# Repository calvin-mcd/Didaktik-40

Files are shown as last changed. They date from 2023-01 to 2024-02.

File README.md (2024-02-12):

# Didaktik 40

The Didaktik 40 is a retro-style keyboard taking its inspiration form the czech homecomputer, the [didaktik gama](https://en.wikipedia.org/wiki/Didaktik#Didaktik_Gama). While offering its original layout, it also supports more modern split and single spacebar bottomrow configurations as well as two rotary encoders.
The case is designed by gizzle13. It is a 2 degree, 2 piece case with top mounting for either simple or burger topmounting. It uses an old-school unified daughterboard for the usb port. The case and pcb furthermore support 2 leds, just like on the original case, and another hole to access the reset button.

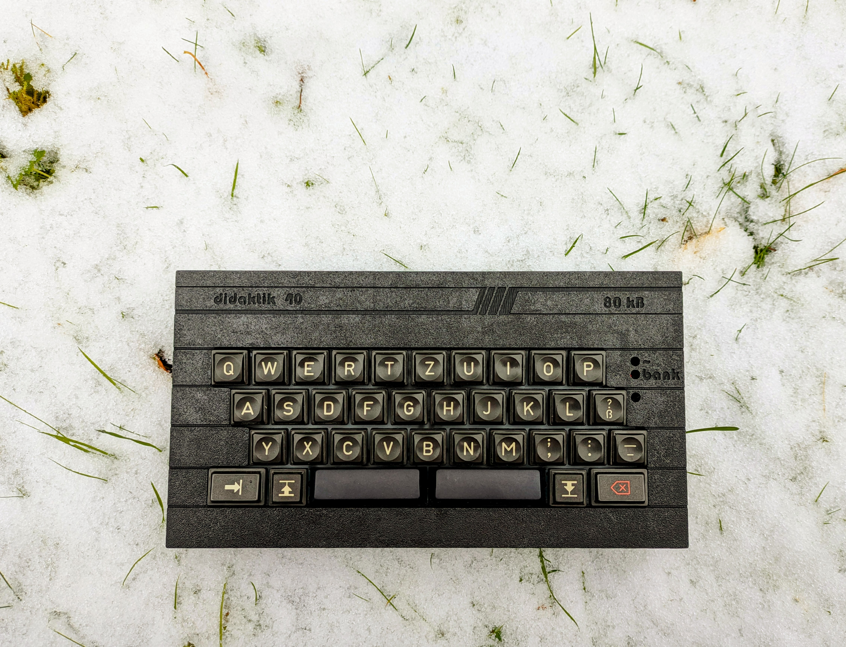
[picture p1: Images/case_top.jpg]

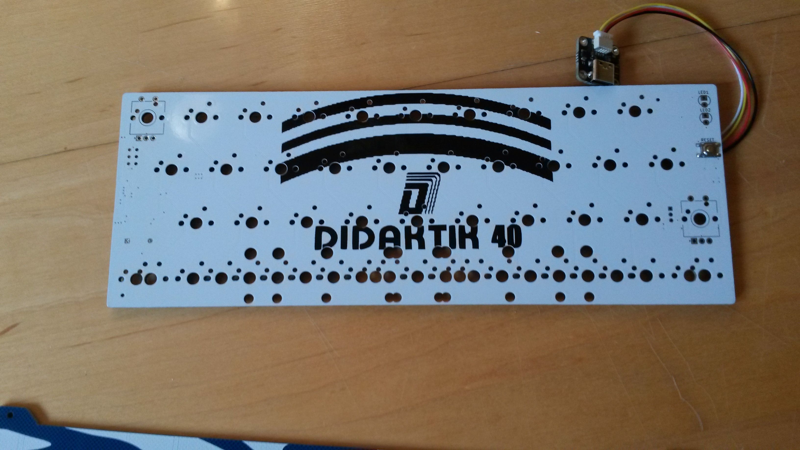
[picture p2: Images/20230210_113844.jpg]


## Layout

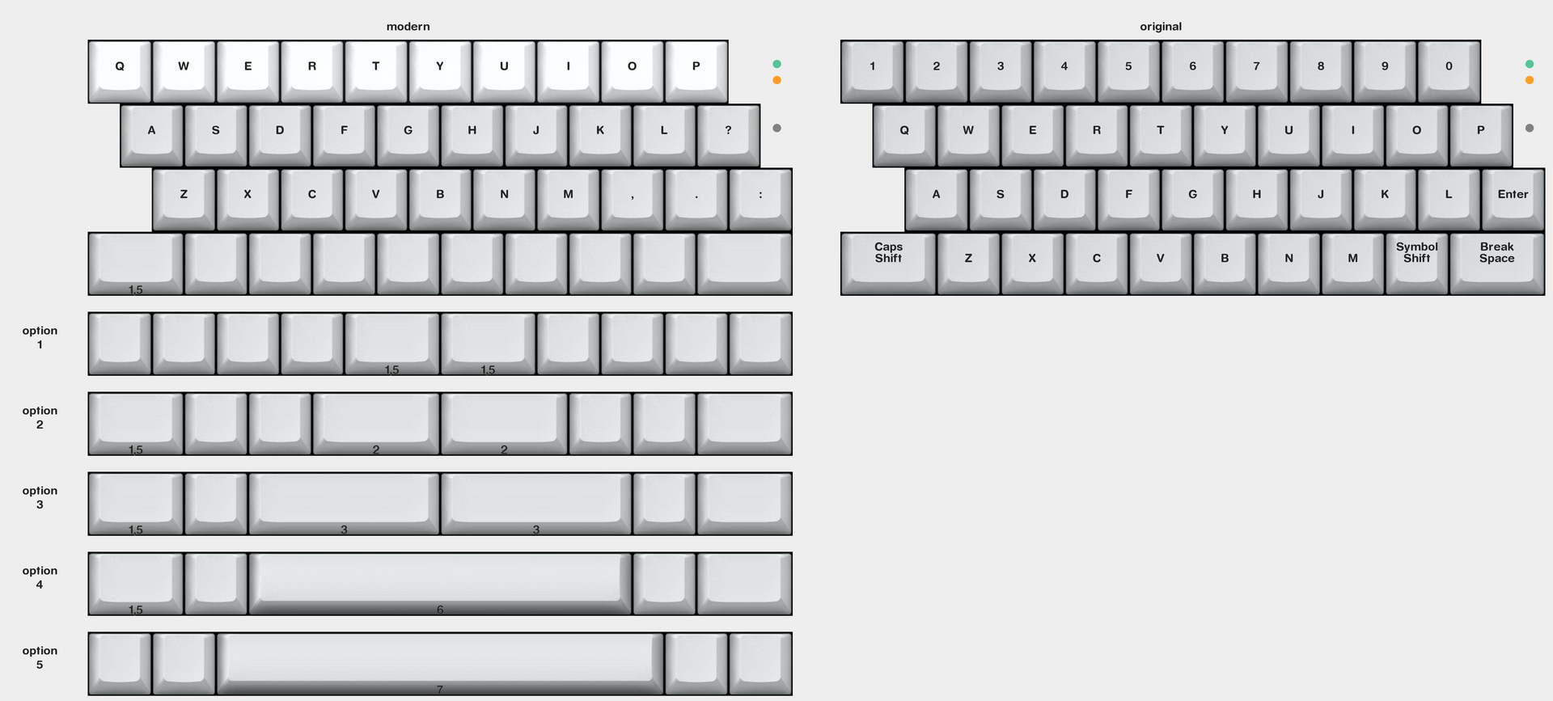
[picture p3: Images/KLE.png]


[Link](http://www.keyboard-layout-editor.com/#/gists/80f2dfd555ef09043852ad12f22f6b8f)

## Firmware

The basic firmware is set up to use the leds as layer indicators. Top for layer 1, bottom for layer 2, both for layer 3. There is hardware support for a speaker and for rgb strip but this is not enabled by default due to firmware size. Also note that the audio and rgb haven't been fully tested yet.

## Case

The case is designed by gizzle13. Case files can be found in the respective folder. It is designed to use m2 heatinserts. 

If you are in the EU consider asking gizzle to print the case for you to support them!

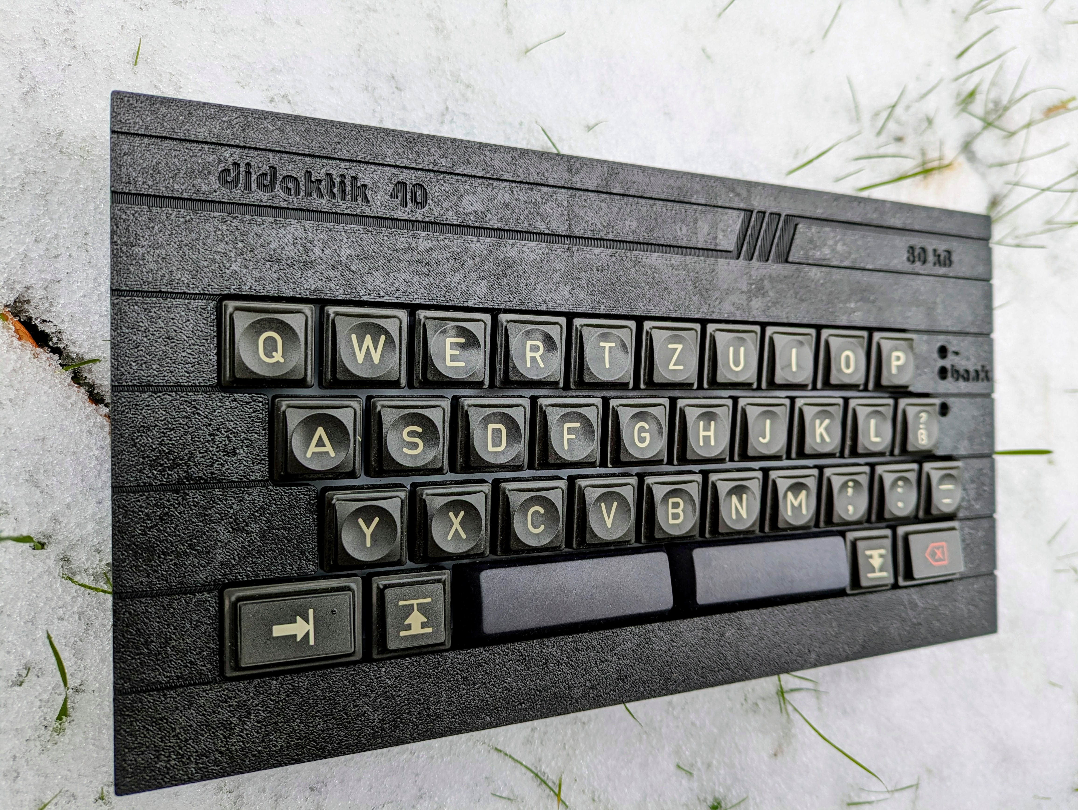
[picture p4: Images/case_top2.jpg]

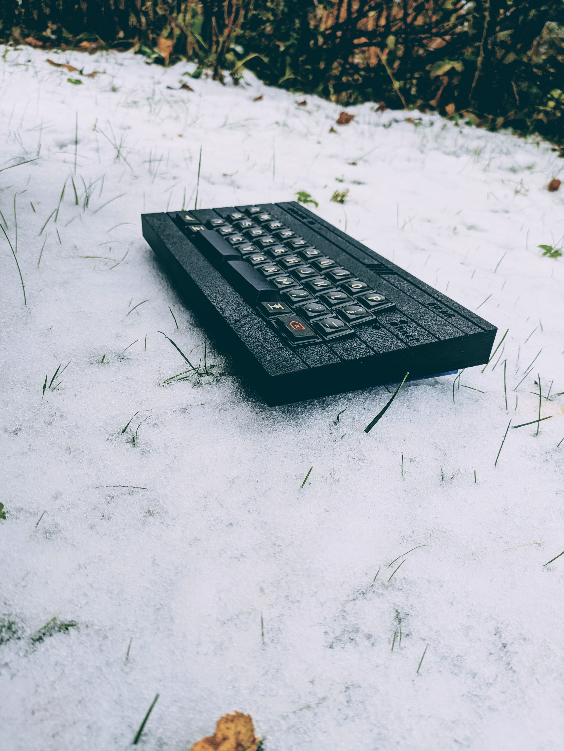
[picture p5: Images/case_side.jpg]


## Disclaimer

This PCB has been fully tested and confirmed to work. The members of the PCB development team are however not liable if you end up with a non-functional pcb. Order at your own risk. Support will not be provided but pull requests will be reviewed and possibly accepted.

## License

This project is released under the GPL v3 License. Please refer to the LICENCE file.

## Credits

big thanks to gizzle13 for making this project possible. The whole idea really lives and thrives with the case!

As always big thanks also to the many people who inspired and helped with this board!

Any questions, contact Calvin0563 on Discord.

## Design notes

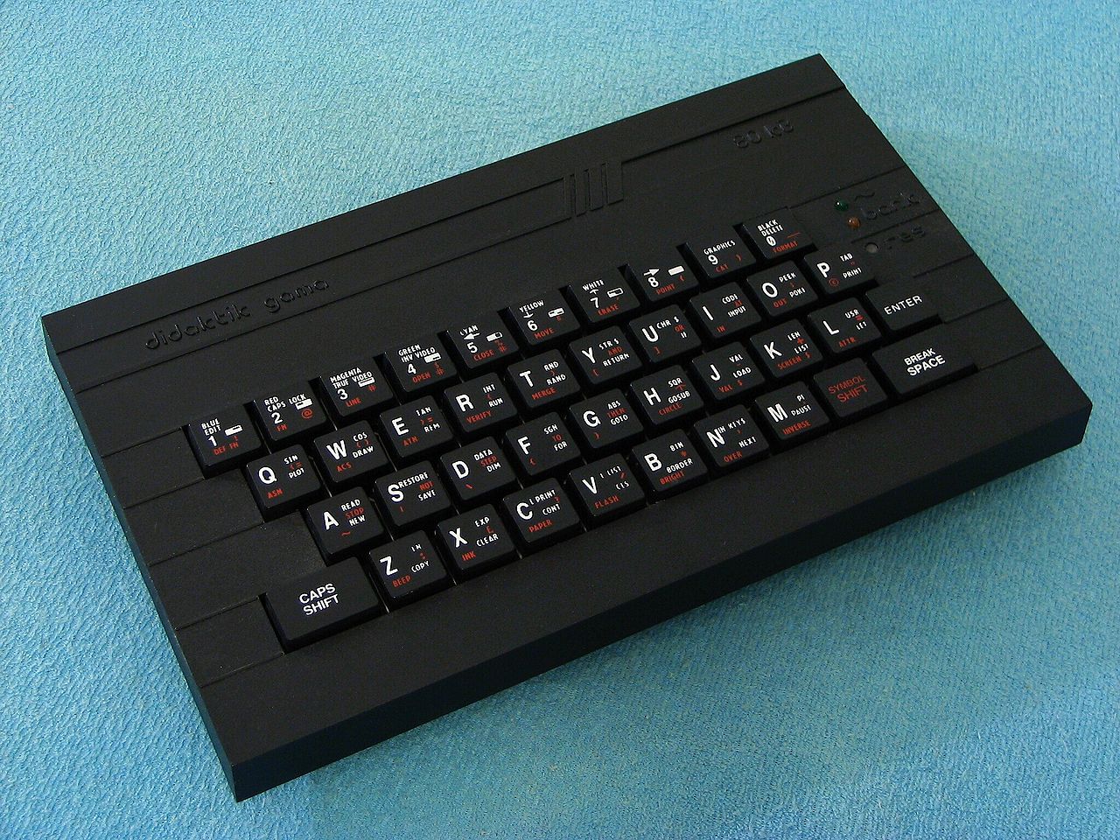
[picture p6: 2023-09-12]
Images/1280px-Didaktik_Gama.jpg

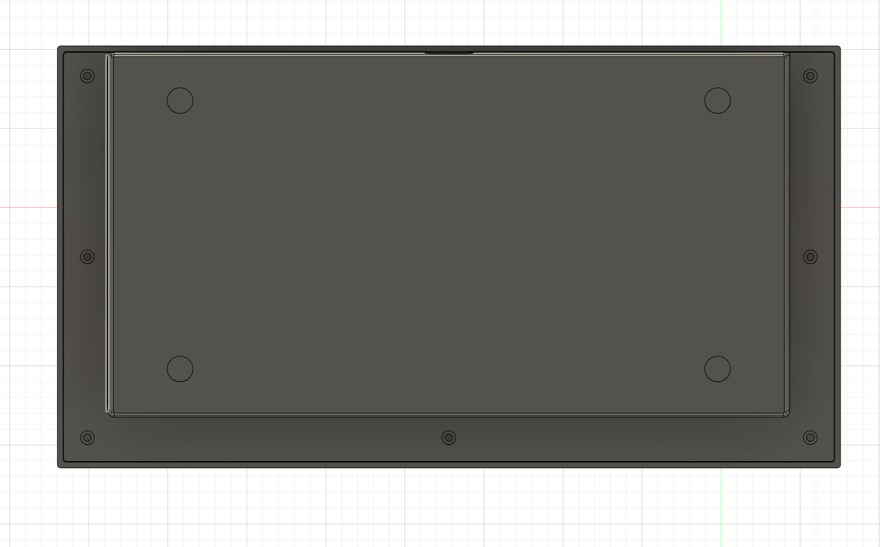
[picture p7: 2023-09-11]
Images/case_wip2.png

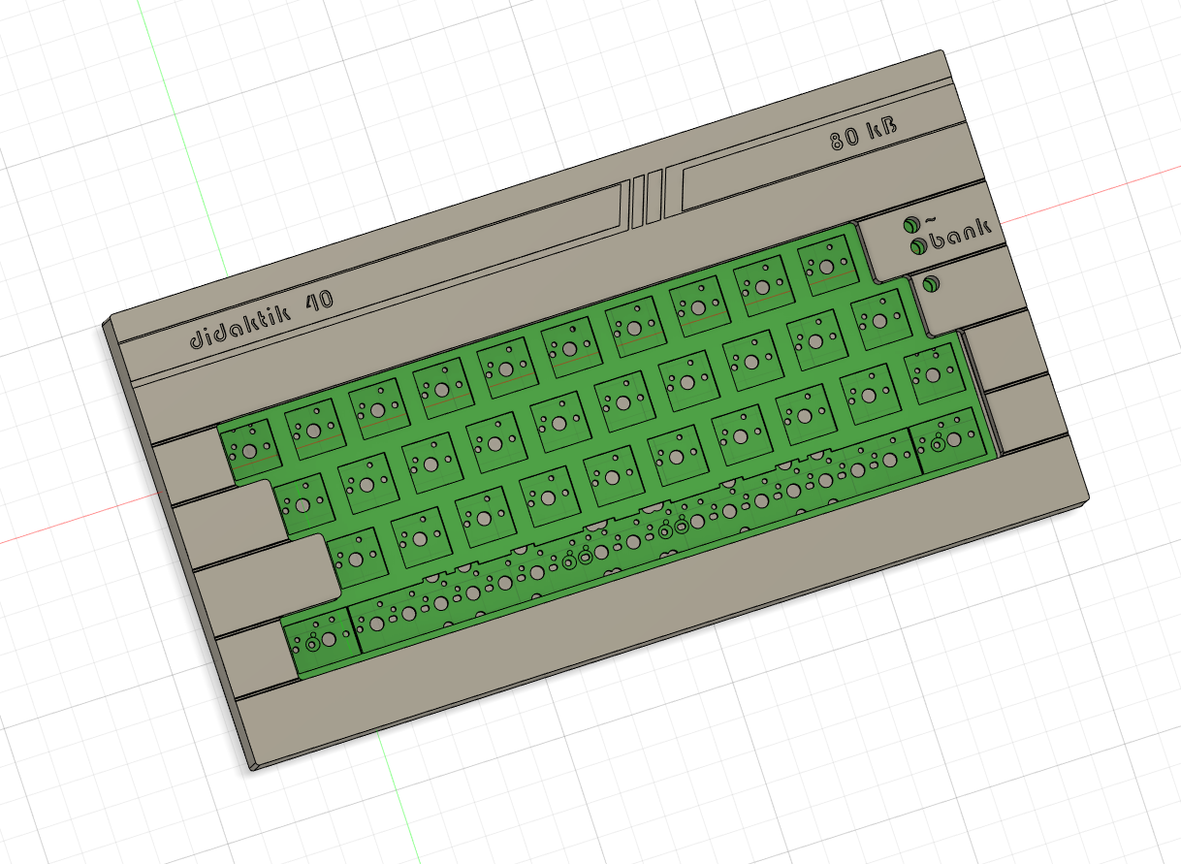
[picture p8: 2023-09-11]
Images/case_wip1.png

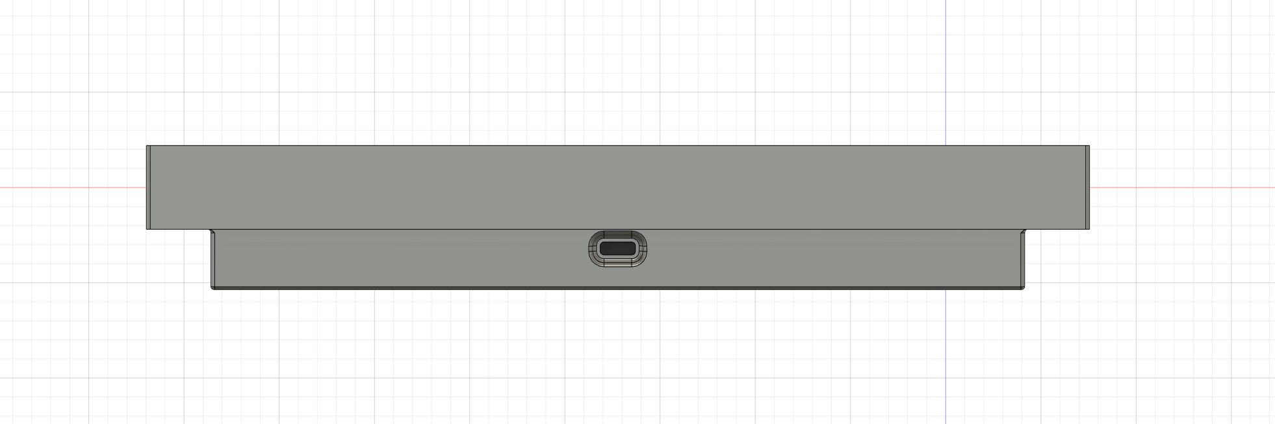
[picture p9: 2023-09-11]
Images/case_wip4.png

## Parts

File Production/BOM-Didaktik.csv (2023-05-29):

Comment | Designator | Footprint | LCSC
22pF | C3,C4 | C_0402_1005Metric | C106203
ATmega32U4-M | U1 | QFN-44-1EP_7x7mm_P0.5mm_EP5.2x5.2mm | C112161
1k | R6 | R_0402_1005Metric | C11702
Crystal_GND24_Small | Y1 | Crystal_SMD_3225-4Pin_3.2x2.5mm | C133336
0.1uF | C1,C2,C5,C7 | C_0402_1005Metric | C1525
Conn_01x04_MountingPin | J1 | JST-SR-4 | C160404
1uF | C6 | C_0402_1005Metric | C182246
2N2222 | Q1 | SOT-23 | C2150
10uF | C8 | C_0402_1005Metric | C237279
22 | R1,R2 | R_0402_1005Metric | C25092
PRTR5V0U2X | D25 | SOT-143 | C2827688
10k | R3,R4 | R_0402_1005Metric | C3015825
220 ohm | R8,R9 | R_0402_1005Metric | C316269
D_Small | D1,D10,D11,D12,D13,D14,D15,D16,D17,D18,D19,D2,D20,D21,D22,D23,D24,D26,D27,D28,D29,D3,D30,D31,D32,D33,D34,D35,D36,D37,D38,D39,D4,D40,D41,D5,D6,D7,D8,D9 | D_SOD-123F | C64898
500mA | F1 | Fuse_1206_3216Metric | C70076
SW_Push_45deg | SW33 | MXOnly-1U-NoLED
SW_Push_45deg | SW15 | MXOnly-1U-NoLED
SW_Push_45deg | SW36c1 | MXOnly-7U-ReversedStabilizers-NoLED
SW_Push_45deg | SW7 | MXOnly-1U-NoLED
SW_Push_45deg | SW27 | MXOnly-1U-NoLED
SW_Push_45deg | SW34b1 | MXOnly-3U-ReversedStabilizers-NoLED
SW_Push_45deg | SW14 | MXOnly-1U-NoLED
SW_Push_45deg | SW33a1 | MXOnly-1U-NoLED
SW_Push_45deg | SW9 | MXOnly-1U-NoLED
LED | D42 | LED_3mm
SW_Push_45deg | SW29 | MXOnly-1U-NoLED
SW_Push_45deg | SW8 | MXOnly-1U-NoLED
SW_Push_45deg | SW35b1 | MXOnly-2U-ReversedStabilizers-NoLED
SW_Push_45deg | SW2 | MXOnly-1U-NoLED
SW_Push_45deg | SW34 | MXOnly-1U-NoLED
SW_Push_45deg | SW24 | MXOnly-1U-NoLED
SW_Push_45deg | SW31 | MXOnly-1.5U-NoLED
SW_Push_45deg | SW37a1 | MXOnly-1U-NoLED
SW_Push_45deg | SW20 | MXOnly-1U-NoLED
SW_Push_45deg | SW5 | MXOnly-1U-NoLED
SW_Push_45deg | SW40a1 | MXOnly-1U-NoLED
SW_Push_45deg | SW35 | MXOnly-1U-NoLED
SW_Push_45deg | SW31a1 | MXOnly-1U-NoLED
SW_Push_45deg | SW38 | MXOnly-1U-NoLED
SW_Push_45deg | SW12 | MXOnly-1U-NoLED
SW_Push_45deg | SW22 | MXOnly-1U-NoLED
SW_Push_45deg | SW36a1 | MXOnly-1.5U-NoLED
SW_Push_45deg | SW36b1 | MXOnly-2U-ReversedStabilizers-NoLED
SW_Push_45deg | SW10 | MXOnly-1U-NoLED
SW_Push_45deg | SW35c1 | MXOnly-6U-Centered-ReversedStabilizers-NoLED
SW_Push_45deg | SW6 | MXOnly-1U-NoLED
SW_Push_45deg | SW19 | MXOnly-1U-NoLED
SW_Push_45deg | SW3 | MXOnly-1U-NoLED
SW_Push_45deg | SW17 | MXOnly-1U-NoLED
SW_Push_45deg | SW39 | MXOnly-1U-NoLED
SW_Push_45deg | SW11 | MXOnly-1U-NoLED
SW_Push_45deg | SW21 | MXOnly-1U-NoLED
SW_Push_45deg | SW16 | MXOnly-1U-NoLED
SW_Push_45deg | SW18 | MXOnly-1U-NoLED
RotaryEncoder_Switch | SW42 | RotaryEncoder_EC11-no-legs
SW_Push_45deg | SW32a1 | MXOnly-1U-NoLED
SW_Push_45deg | SW37b1 | MXOnly-3U-ReversedStabilizers-NoLED
SW_Push_45deg | SW34a1 | MXOnly-1U-NoLED
SW_Push_45deg | SW36 | MXOnly-1U-NoLED
SW_Push_45deg | SW28 | MXOnly-1U-NoLED
SW_Push_45deg | SW1 | MXOnly-1U-NoLED
SW_Push_45deg | SW40 | MXOnly-1.5U-NoLED
SW_Push_45deg | SW39a1 | MXOnly-1U-NoLED
SW_Push_45deg | SW37 | MXOnly-1U-NoLED
SW_Push_45deg | SW4 | MXOnly-1U-NoLED
SW_Push_45deg | SW35a1 | MXOnly-1.5U-NoLED
SW_Push_45deg | SW32 | MXOnly-1U-NoLED
SW_Push_45deg | SW26 | MXOnly-1U-NoLED
SW_Push_45deg | SW30 | MXOnly-1U-NoLED
SW_Push_45deg | SW38a1 | MXOnly-1U-NoLED
SW_Push_45deg | SW13 | MXOnly-1U-NoLED
RotaryEncoder_Switch | SW41 | RotaryEncoder_EC11-no-legs
SW_Push_45deg | SW25 | MXOnly-1U-NoLED
SW_Push_45deg | SW23 | MXOnly-1U-NoLED
Conn_01x03 | J3 | PinSocket_1x03_P2.00mm_Vertical
Speaker | LS1 | AST1109MLTRQ
1k | R5 | Diode-Hybrid-Back
LED | D43 | LED_3mm
SW_Push | SW_Reset1 | SKQG-1155865
AVR-ISP-6 | J2 | Reset_Pretty-Mask

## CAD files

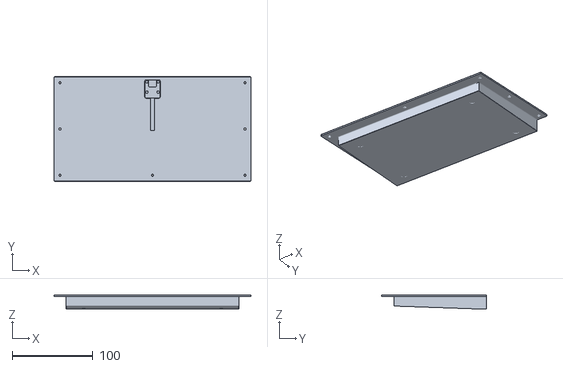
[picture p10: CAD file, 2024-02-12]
Case/Bottom.stl
243.6 x 129.4 x 17.9

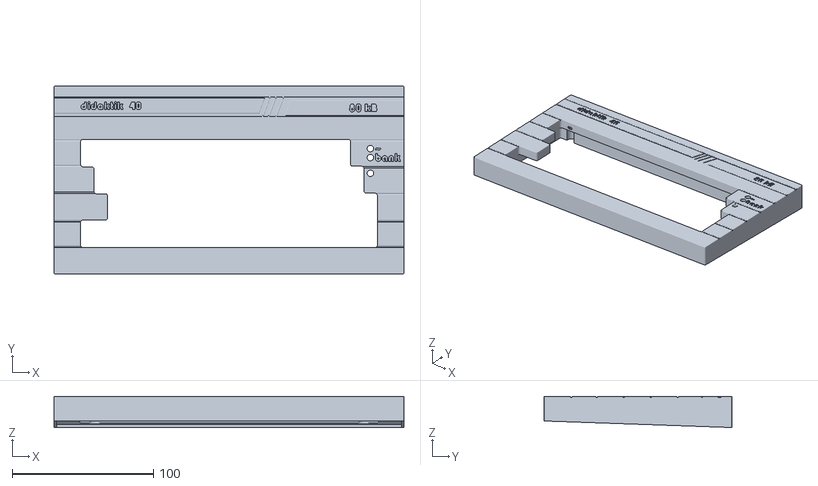
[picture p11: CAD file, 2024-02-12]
Case/Top.stl
247.6 x 133.4 x 22.0

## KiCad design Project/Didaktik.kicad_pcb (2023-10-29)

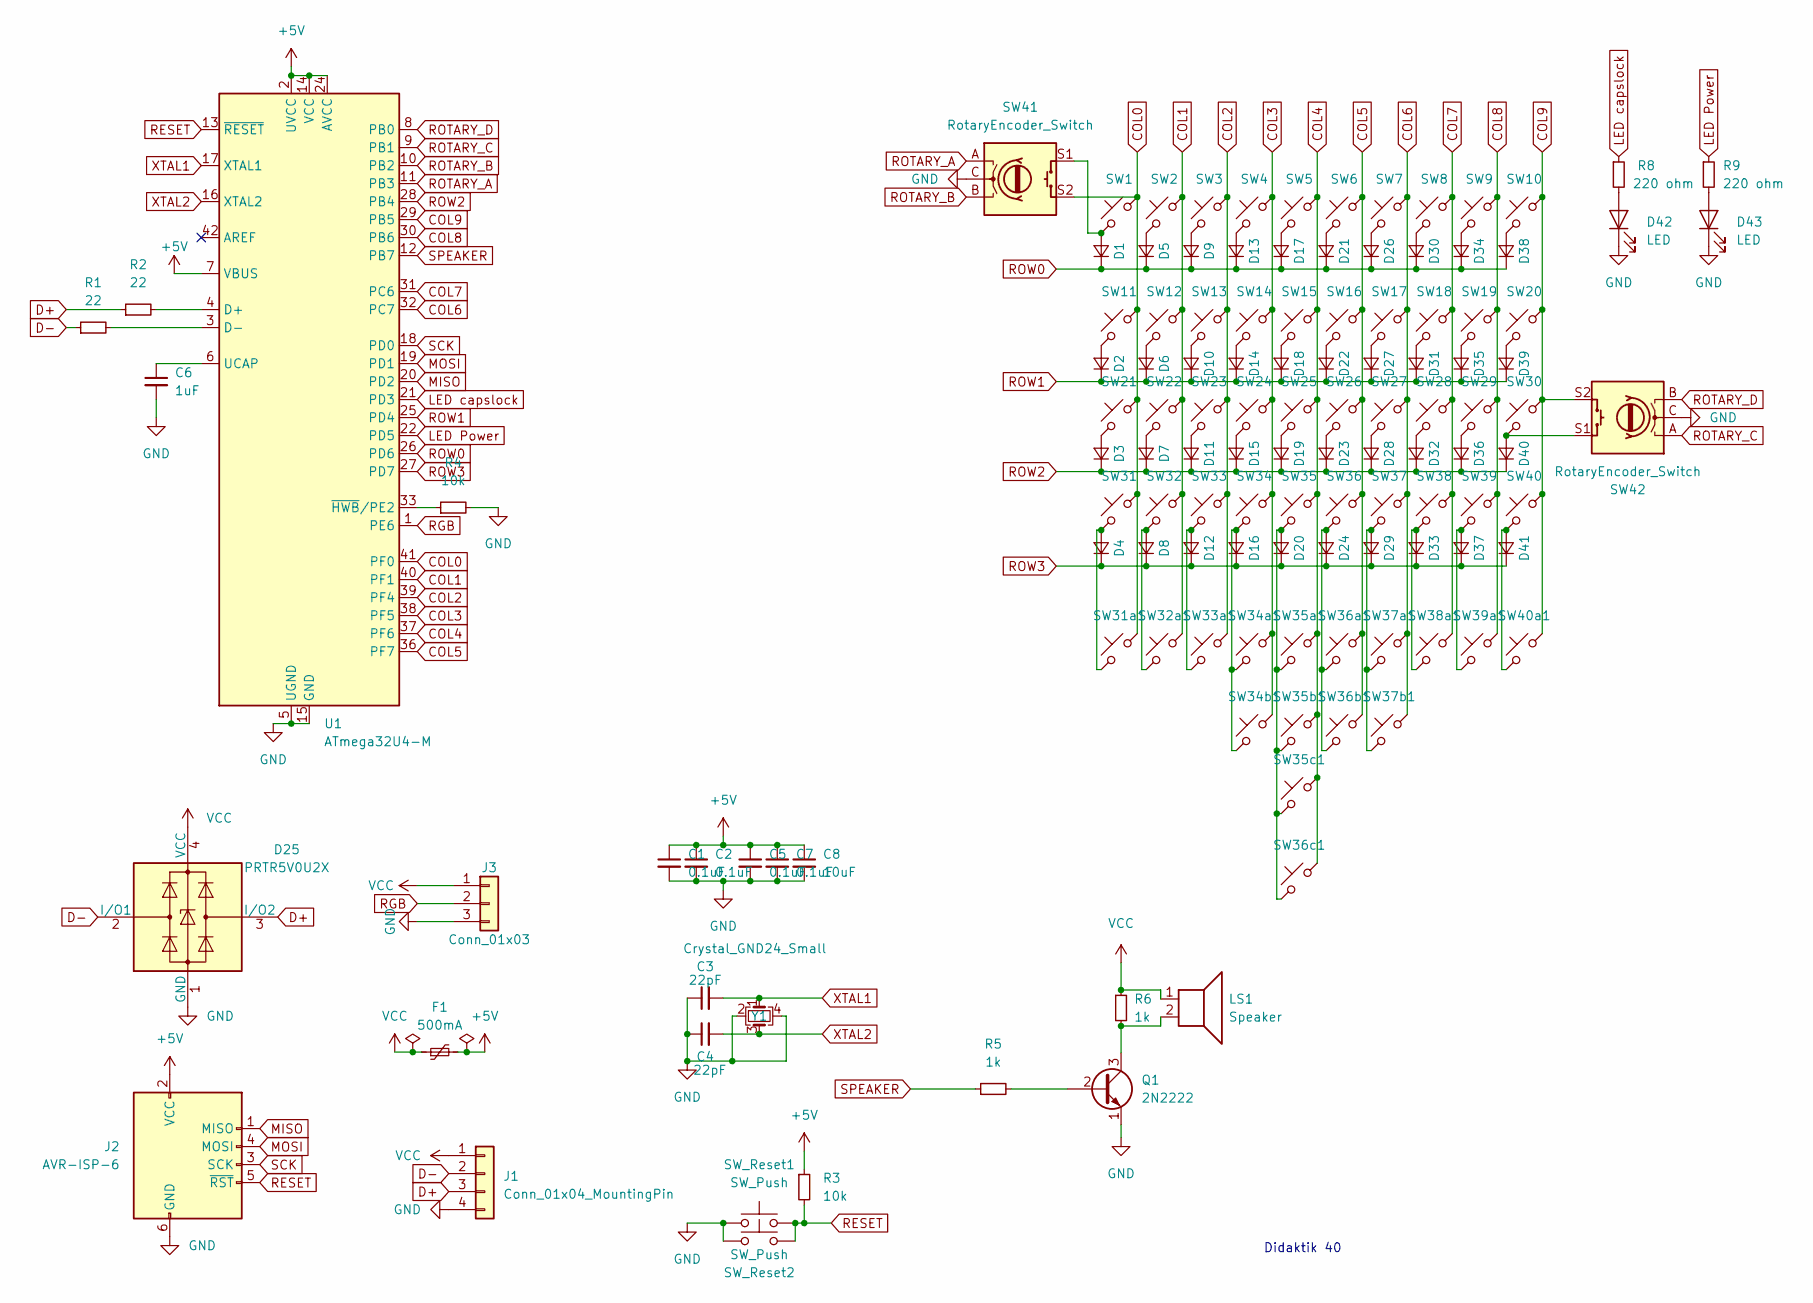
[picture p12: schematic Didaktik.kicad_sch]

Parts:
C1, C2, C5, C7: 0.1uF; C_0402_1005Metric
C3, C4: 22pF; C_0402_1005Metric
C6: 1uF; C_0402_1005Metric
C8: 10uF; C_0402_1005Metric
D1, D2, D3, D4, D5, D6, D7, D8, D9, D10, D11, D12, D13, D14, D15, D16, D17, D18, D19, D20, D21, D22, D23, D24, D26, D27, D28, D29, D30, D31, D32, D33, D34, D35, D36, D37, D38, D39, D40, D41: D_Small; D_SOD-123F
D25: PRTR5V0U2X; SOT-143
D42, D43: LED; LED_3mm
F1: 500mA; Fuse_1206_3216Metric
J1: Conn_01x04_MountingPin; JST-SR-4
J2: AVR-ISP-6; Reset_Pretty-Mask
J3: Conn_01x03; PinSocket_1x03_P2.00mm_Vertical
LS1: Speaker; AST1109MLTRQ
Q1: 2N2222; SOT-23
R1, R2: 22; R_0402_1005Metric
R3, R4: 10k; R_0402_1005Metric
R5: 1k; Diode-Hybrid-Back
R6: 1k; R_0402_1005Metric
R8, R9: 220 ohm; R_0402_1005Metric
SW1, SW2, SW3, SW4, SW5, SW6, SW7, SW8, SW9, SW10, SW11, SW12, SW13, SW14, SW15, SW16, SW17, SW18, SW19, SW20, SW21, SW22, SW23, SW24, SW25, SW26, SW27, SW28, SW29, SW30, SW31a1, SW32, SW32a1, SW33, SW33a1, SW34, SW34a1, SW35, SW36, SW37, SW37a1, SW38, SW38a1, SW39, SW39a1, SW40a1: SW_Push_45deg; MXOnly-1U-NoLED
SW31, SW35a1, SW36a1, SW40: SW_Push_45deg; MXOnly-1.5U-NoLED
SW34b1, SW37b1: SW_Push_45deg; MXOnly-3U-ReversedStabilizers-NoLED
SW35b1, SW36b1: SW_Push_45deg; MXOnly-2U-ReversedStabilizers-NoLED
SW35c1: SW_Push_45deg; MXOnly-6U-Centered-ReversedStabilizers-NoLED
SW36c1: SW_Push_45deg; MXOnly-7U-ReversedStabilizers-NoLED
SW41, SW42: RotaryEncoder_Switch; RotaryEncoder_EC11-no-legs
SW_Reset1: SW_Push; SKQG-1155865
SW_Reset2: SW_Push; PinHeader_1x02_P2.54mm_Vertical
U1: ATmega32U4-M; QFN-44-1EP_7x7mm_P0.5mm_EP5.2x5.2mm
Y1: Crystal_GND24_Small; Crystal_SMD_3225-4Pin_3.2x2.5mm

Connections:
+5V: C1.1, C2.1, C5.1, C7.1, C8.1, F1.2, J2.2 (VCC), R3.1, U1.2 (UVCC), U1.7 (VBUS), U1.14 (VCC), U1.24 (AVCC), U1.34 (VCC), U1.44 (AVCC)
COL0: SW1.1, SW11.1, SW21.1, SW31.1, SW31a1.1, SW41.S2, U1.41 (PF0)
COL1: SW2.1, SW12.1, SW22.1, SW32.1, SW32a1.1, U1.40 (PF1)
COL2: SW3.1, SW13.1, SW23.1, SW33.1, SW33a1.1, U1.39 (PF4)
COL3: SW4.1, SW14.1, SW24.1, SW34.1, SW34a1.1, SW34b1.1, U1.38 (PF5)
COL4: SW5.1, SW15.1, SW25.1, SW35.1, SW35a1.1, SW35b1.1, SW35c1.1, SW36c1.1, U1.37 (PF6)
COL5: SW6.1, SW16.1, SW26.1, SW36.1, SW36a1.1, SW36b1.1, U1.36 (PF7)
COL6: SW7.1, SW17.1, SW27.1, SW37.1, SW37a1.1, SW37b1.1, U1.32 (PC7)
COL7: SW8.1, SW18.1, SW28.1, SW38.1, SW38a1.1, U1.31 (PC6)
COL8: SW9.1, SW19.1, SW29.1, SW39.1, SW39a1.1, U1.30 (PB6)
COL9: SW10.1, SW20.1, SW30.1, SW40.1, SW40a1.1, SW42.S2, U1.29 (PB5)
D+: D25.3 (I/O2), J1.3, R2.1
D-: D25.2 (I/O1), J1.2, R1.1
GND: C1.2, C2.2, C3.1, C4.1, C5.2, C6.2, C7.2, C8.2, D25.1 (GND), D42.1 (K), D43.1 (K), J1.4, J2.6 (GND), J3.3, Q1.1 (E), R4.2, SW41.C, SW42.C, SW_Reset1.1, SW_Reset2.1, U1.5 (UGND), U1.15 (GND), U1.23 (GND), U1.35 (GND), U1.43 (GND), U1.45 (GND), Y1.2, Y1.4
LED Power: R9.1, U1.22 (PD5)
LED capslock: R8.1, U1.21 (PD3)
MISO: J2.1 (MISO), U1.20 (PD2)
MOSI: J2.4 (MOSI), U1.19 (PD1)
unnamed: D1.2 (A), SW1.2, SW41.S1
unnamed: D2.2 (A), SW11.2
unnamed: D3.2 (A), SW21.2
unnamed: D4.2 (A), SW31.2, SW31a1.2
unnamed: D5.2 (A), SW2.2
unnamed: D6.2 (A), SW12.2
unnamed: D7.2 (A), SW22.2
unnamed: D8.2 (A), SW32.2, SW32a1.2
unnamed: D9.2 (A), SW3.2
unnamed: D10.2 (A), SW13.2
unnamed: D11.2 (A), SW23.2
unnamed: D12.2 (A), SW33.2, SW33a1.2
unnamed: D13.2 (A), SW4.2
unnamed: D14.2 (A), SW14.2
unnamed: D15.2 (A), SW24.2
unnamed: D16.2 (A), SW34.2, SW34a1.2, SW34b1.2
unnamed: D17.2 (A), SW5.2
unnamed: D18.2 (A), SW15.2
unnamed: D19.2 (A), SW25.2
unnamed: D20.2 (A), SW35.2, SW35a1.2, SW35b1.2, SW35c1.2, SW36c1.2
unnamed: D21.2 (A), SW6.2
unnamed: D22.2 (A), SW16.2
unnamed: D23.2 (A), SW26.2
unnamed: D24.2 (A), SW36.2, SW36a1.2, SW36b1.2
unnamed: D26.2 (A), SW7.2
unnamed: D27.2 (A), SW17.2
unnamed: D28.2 (A), SW27.2
unnamed: D29.2 (A), SW37.2, SW37a1.2, SW37b1.2
unnamed: D30.2 (A), SW8.2
unnamed: D31.2 (A), SW18.2
unnamed: D32.2 (A), SW28.2
unnamed: D33.2 (A), SW38.2, SW38a1.2
unnamed: D34.2 (A), SW9.2
unnamed: D35.2 (A), SW19.2
unnamed: D36.2 (A), SW29.2
unnamed: D37.2 (A), SW39.2, SW39a1.2
unnamed: D38.2 (A), SW10.2
unnamed: D39.2 (A), SW20.2
unnamed: D40.2 (A), SW30.2, SW42.S1
unnamed: D41.2 (A), SW40.2, SW40a1.2
unnamed: D42.2 (A), R8.2
unnamed: D43.2 (A), R9.2
unnamed: Q1.2 (B), R5.2
unnamed: LS1.2, Q1.3 (C), R6.2
unnamed: R2.2, U1.4 (D+)
unnamed: R1.2, U1.3 (D-)
unnamed: C6.1, U1.6 (UCAP)
unnamed: R4.1, U1.33 (~HWB/PE2)
RESET: J2.5 (~RST), R3.2, SW_Reset1.2, SW_Reset2.2, U1.13 (~RESET)
RGB: J3.2, U1.1 (PE6)
ROTARY_A: SW41.A, U1.11 (PB3)
ROTARY_B: SW41.B, U1.10 (PB2)
ROTARY_C: SW42.A, U1.9 (PB1)
ROTARY_D: SW42.B, U1.8 (PB0)
ROW0: D1.1 (K), D5.1 (K), D9.1 (K), D13.1 (K), D17.1 (K), D21.1 (K), D26.1 (K), D30.1 (K), D34.1 (K), D38.1 (K), U1.26 (PD6)
ROW1: D2.1 (K), D6.1 (K), D10.1 (K), D14.1 (K), D18.1 (K), D22.1 (K), D27.1 (K), D31.1 (K), D35.1 (K), D39.1 (K), U1.25 (PD4)
ROW2: D3.1 (K), D7.1 (K), D11.1 (K), D15.1 (K), D19.1 (K), D23.1 (K), D28.1 (K), D32.1 (K), D36.1 (K), D40.1 (K), U1.28 (PB4)
ROW3: D4.1 (K), D8.1 (K), D12.1 (K), D16.1 (K), D20.1 (K), D24.1 (K), D29.1 (K), D33.1 (K), D37.1 (K), D41.1 (K), U1.27 (PD7)
SCK: J2.3 (SCK), U1.18 (PD0)
SPEAKER: R5.1, U1.12 (PB7)
VCC: D25.4 (VCC), F1.1, J1.1, J3.1, LS1.1, R6.1
XTAL1: C3.2, U1.17 (XTAL1), Y1.1
XTAL2: C4.2, U1.16 (XTAL2), Y1.3

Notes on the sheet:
Didaktik 40

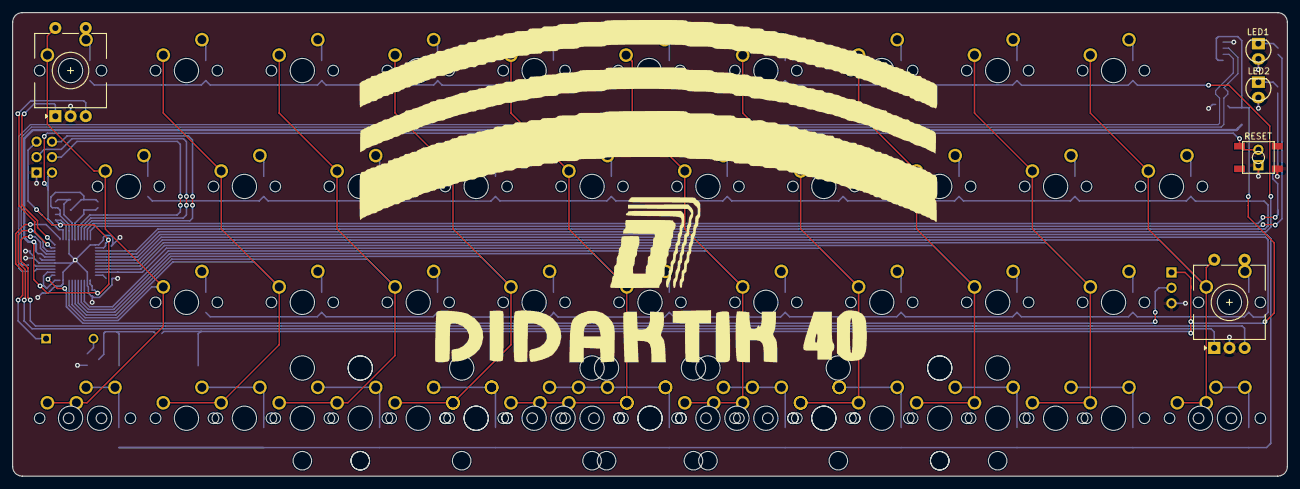
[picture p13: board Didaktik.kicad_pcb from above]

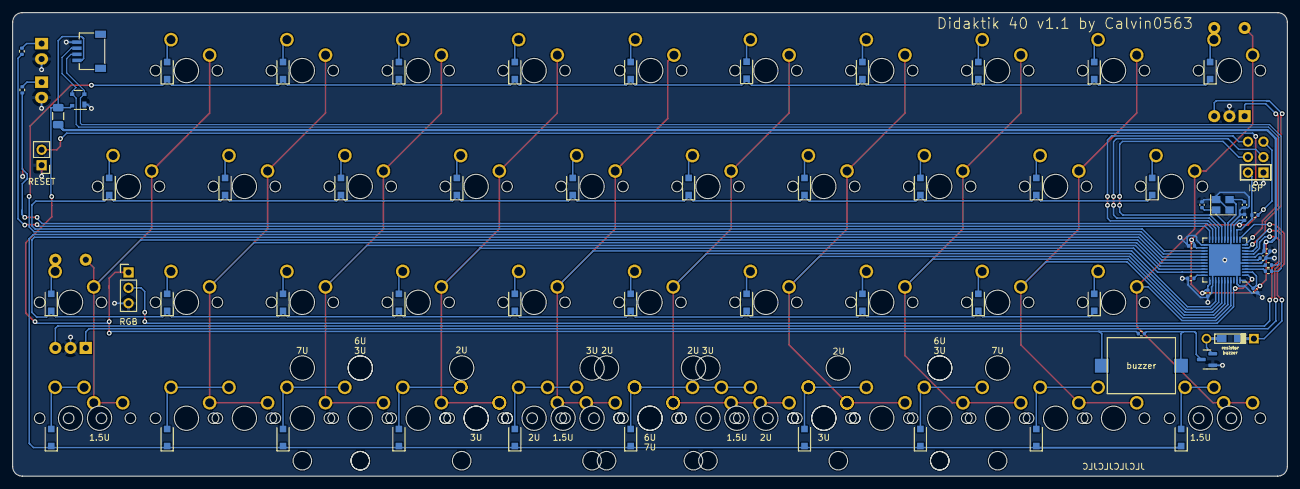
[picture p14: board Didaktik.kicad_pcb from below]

Board: 2 copper layers, 209.6 x 76.2 mm, 127 parts (65 on the bottom side), 81 nets.

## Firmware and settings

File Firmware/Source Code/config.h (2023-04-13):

#pragma once

#include "config_common.h"

#define ENCODERS_PAD_A { B3, B1 }
#define ENCODERS_PAD_B { B2, B0 }

#define AUDIO_PIN B7

#define LED0_PIN D5
#define LED1_PIN D3

#undef LOCKING_SUPPORT_ENABLE
#undef LOCKING_RESYNC_ENABLE

#define NO_ACTION_ONESHOT
#define LAYER_STATE_8BIT

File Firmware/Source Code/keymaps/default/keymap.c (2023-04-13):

#include QMK_KEYBOARD_H

const uint16_t PROGMEM keymaps[][MATRIX_ROWS][MATRIX_COLS] = {

	[0] = LAYOUT(
		KC_1, 	 KC_2,	  KC_3,	   KC_4,	KC_5,	 KC_6,	  KC_7,	   KC_8,	KC_9,	 KC_0,
		KC_Q,    KC_W,    KC_E,    KC_R,    KC_T,    KC_Y,    KC_U,    KC_I,    KC_O,    KC_P,    
		KC_A,    KC_S,    KC_D,    KC_F,    KC_G,    KC_H,    KC_J,    KC_K,    KC_L,    KC_ENT, 
		KC_LSFT, KC_Z,    KC_X,    KC_C,    KC_V,    KC_B,    KC_N,    KC_M,    KC_LEFT_GUI, KC_BSPC
	),

	[1] = LAYOUT(
		KC_TRNS, KC_TRNS, KC_TRNS, KC_TRNS, KC_TRNS, KC_TRNS, KC_TRNS, KC_TRNS, KC_TRNS, KC_TRNS, 
		KC_TRNS, KC_TRNS, KC_TRNS, KC_TRNS, KC_TRNS, KC_TRNS, KC_TRNS, KC_TRNS, KC_TRNS, KC_TRNS, 
		KC_TRNS, KC_TRNS, KC_TRNS, KC_TRNS, KC_TRNS, KC_TRNS, KC_TRNS, KC_TRNS, KC_TRNS, KC_TRNS, 
		KC_TRNS, KC_TRNS, KC_TRNS, KC_TRNS, KC_TRNS, KC_TRNS, KC_TRNS, KC_TRNS, KC_TRNS, KC_TRNS
	),

	[2] = LAYOUT(
		KC_TRNS, KC_TRNS, KC_TRNS, KC_TRNS, KC_TRNS, KC_TRNS, KC_TRNS, KC_TRNS, KC_TRNS, KC_TRNS, 
		KC_TRNS, KC_TRNS, KC_TRNS, KC_TRNS, KC_TRNS, KC_TRNS, KC_TRNS, KC_TRNS, KC_TRNS, KC_TRNS, 
		KC_TRNS, KC_TRNS, KC_TRNS, KC_TRNS, KC_TRNS, KC_TRNS, KC_TRNS, KC_TRNS, KC_TRNS, KC_TRNS, 
		KC_TRNS, KC_TRNS, KC_TRNS, KC_TRNS, KC_TRNS, KC_TRNS, KC_TRNS, KC_TRNS, KC_TRNS, KC_TRNS
	),

	[3] = LAYOUT(
		KC_TRNS, KC_TRNS, KC_TRNS, KC_TRNS, KC_TRNS, KC_TRNS, KC_TRNS, KC_TRNS, KC_TRNS, KC_TRNS, 
		KC_TRNS, KC_TRNS, KC_TRNS, KC_TRNS, KC_TRNS, KC_TRNS, KC_TRNS, KC_TRNS, KC_TRNS, KC_TRNS, 
		KC_TRNS, KC_TRNS, KC_TRNS, KC_TRNS, KC_TRNS, KC_TRNS, KC_TRNS, KC_TRNS, KC_TRNS, KC_TRNS, 
		KC_TRNS, KC_TRNS, KC_TRNS, KC_TRNS, KC_TRNS, KC_TRNS, KC_TRNS, KC_TRNS, KC_TRNS, KC_TRNS
	)
};

/* Encoder */ 
const uint16_t PROGMEM encoder_map[][NUM_ENCODERS][2] = {
    [0] = { ENCODER_CCW_CW(KC_NO, KC_NO), ENCODER_CCW_CW(KC_NO, KC_NO) },
    [1] = { ENCODER_CCW_CW(KC_NO, KC_NO), ENCODER_CCW_CW(KC_NO, KC_NO) },
    [2] = { ENCODER_CCW_CW(KC_NO, KC_NO), ENCODER_CCW_CW(KC_NO, KC_NO) },
    [3] = { ENCODER_CCW_CW(KC_NO, KC_NO), ENCODER_CCW_CW(KC_NO, KC_NO) }
};


//LED indicators

void show_layer_on_leds(layer_state_t state) {
    switch (get_highest_layer(state)) {
    case 1:
        writePinHigh(LED0_PIN);
        writePinLow(LED1_PIN);
        break;

    case 2:
        writePinLow(LED0_PIN);
        writePinHigh(LED1_PIN);
        break;

    case 3:
        writePinHigh(LED0_PIN);
        writePinHigh(LED1_PIN);
        break;

    default: //  for any other layers, or the default layer
        writePinLow(LED0_PIN);
        writePinLow(LED1_PIN);
        break;
    }
}

layer_state_t layer_state_set_user(layer_state_t state) {
    show_layer_on_leds(state);
    return state;
}

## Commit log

2022-10-15 initial commit
    setting up libraries
    [Didaktik.kicad_pcb, Didaktik.kicad_sch]
2022-10-20 switch placement done, basic matrix routing done
    [Didaktik.kicad_pcb, Didaktik.kicad_sch, Didaktik45.kicad_sch]
2022-10-20 added jts, started to arrange MCU components
    [Didaktik.kicad_pcb, Didaktik.kicad_sch]
2022-10-23 added leds
    [Didaktik.kicad_pcb, Didaktik.kicad_sch]
2022-10-23 cleaned schematics, continued routing
    [Didaktik.kicad_pcb, Didaktik.kicad_sch]
2022-10-23 all traces routed, schematics cleaned up
    [Didaktik.kicad_pcb, Didaktik.kicad_sch]
2022-10-23 full routing, silkscreens, zones
    [Didaktik.kicad_pcb, Didaktik.kicad_sch]
2022-10-23 created switchplate 40, cleaned 40s pcb. finished schematics for 45. created pcb project for 45
    [Didaktik switchplate.kicad_pcb, Didaktik.kicad_pcb, Didaktik.kicad_sch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]
2022-10-23 D45 & D40 pcbs created & cleaned. D45 plate created
    [Didaktik.kicad_pcb, Didaktik45 switchplate.kicad_pcb, Didaktik45.kicad_pcb]
2022-10-24 added ISP to 40, added ISP schematics to 45
    [Didaktik switchplate.step, Didaktik.kicad_pcb, Didaktik.kicad_sch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]
2022-10-25 cleaned up some traces, ran DRC
    [Didaktik.kicad_pcb]
2022-10-25 slight alterations to routes
    changing rounded for sharp ones
    [Didaktik45.kicad_pcb]
2022-10-26 created small tap plate, exported all plates and pcb in step for case design
    [Didaktik ppcb.step, Didaktik switchplate narrow.kicad_pcb, Didaktik switchplate small taps.step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]
2022-10-26 moved step into its own folder
    [Didaktik ppcb.step, Didaktik switchplate small taps.step, Didaktik switchplate.step]
2022-10-30 added multi layout proto
    [Didaktik multilayout proto.kicad_pcb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]
2022-11-10 updated routing, created footprints for bottom row
    [Didaktik.kicad_pcb, Didaktik.kicad_sch]
2022-11-10 cleaned routing, added multilayout to schematics and laid out footprints under the pcb
    [Didaktik.kicad_pcb, Didaktik.kicad_sch]
2022-11-12 added multi layout pcb, kept original
    [Didaktik multilayout.kicad_pcb]
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2022-11-12 set up multilayout
    need to check if all switches are really routed
    maybe get rid of 2U
    [Didaktik multilayout proto.kicad_pcb, Didaktik multilayout.kicad_pcb, Didaktik multilayout.kicad_sch]
2022-11-18 cleaning up the schematics / pcb for multi
    [Didaktik multilayout.kicad_pcb]
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2022-11-26 simplifying schematics, rerouting pcb
    [Didaktik multilayout.kicad_pcb, Didaktik multilayout.kicad_sch]
2022-11-27 routing new simpler matrix on pcb
    [Didaktik multilayout.kicad_pcb, Didaktik multilayout.kicad_sch]
2022-12-11 pcb copy, footprint revision, rerouting needed
    [Didaktik multilayout old.kicad_pcb, Didaktik multilayout.kicad_sch]
2022-12-11 redoing placement, first routing line tests
    [Didaktik multilayout.kicad_pcb]
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2022-12-11 reworking mcu placement and wiring
    [Didaktik multilayout.kicad_pcb]
2022-12-12 full routing of mcu & matrix
    [Didaktik multilayout switchplate.kicad_pcb, Didaktik multilayout.kicad_pcb, Didaktik multilayout.kicad_sch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]
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2022-12-13 outlined case more, deliberating routing aesthetics
    [Didaktik multilayout.kicad_pcb]
2022-12-14 cleaning up pcb & switch plate edge cut
    [Didaktik multilayout switchplate.kicad_pcb, Didaktik multilayout.kicad_pcb]
2022-12-16 redoing JST placement, some routing, full boardGND fill
    [Didaktik multilayout switchplate.kicad_pcb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]
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2022-12-20 adding rotaries & rgb breakout
    [Didaktik multilayout.kicad_pcb, Didaktik multilayout.kicad_sch]
2022-12-22 added buzzer
    [Didaktik multilayout-B_Cu.gbr, Didaktik multilayout-B_Mask.gbr, Didaktik multilayout-B_Paste.gbr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]
2022-12-22 created production files, pdfs for review
    [Didaktik multilayout-B_Cu.gbr, Didaktik multilayout-B_Mask.gbr, Didaktik multilayout-B_Paste.gbr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]
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2022-12-27 cleaned up routing
    sudden 9th error isp ground via to gnd net?
    [Didaktik multilayout-B_Cu.gbr, Didaktik multilayout-B_Mask.gbr, Didaktik multilayout-B_Paste.gbr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]
2022-12-27 trying to export plate files
    [Didaktik multilayout-B_Cu.gbr, Didaktik multilayout-B_Mask.gbr, Didaktik multilayout-B_Paste.gbr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]
2023-01-02 edited buzzer schematics & pcb placement
    [Didaktik multilayout switchplate-B_Cu.gbr, Didaktik multilayout switchplate-B_Mask.gbr, Didaktik multilayout switchplate-B_Paste.gbr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]
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2023-01-07 changed sod123 to sod123f
    [Didaktik multilayout.kicad_pcb, Didaktik multilayout.kicad_sch]
2023-01-08 rgb pin changed from 42 to 1, new production files
    [Didaktik multilayout-B_Cu.gbr, Didaktik multilayout-B_Mask.gbr, Didaktik multilayout-B_Paste.gbr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]
2023-01-26 V1.1
    added double reset button, pinout
    [Didaktik multilayout-B_Cu.gbr, Didaktik multilayout-B_Mask.gbr, Didaktik multilayout-B_Paste.gbr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]
2023-01-26 V1.1 Reset Button finished
    cleaned project folder
    [Didaktik multilayout-B_Cu.gbr, Didaktik multilayout-B_Mask.gbr, Didaktik multilayout-B_Paste.gbr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]
2023-02-18 clean up folders, created rp2040 version
    [Didaktik rp2040.kicad_pcb, Didaktik rp2040.kicad_sch, Didaktik switchplate.kicad_pcb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]
2023-02-19 switch and matrix components placed
    [Didaktik rp2040.kicad_pcb, components.kicad_sch]
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2023-02-20 some more cleaner MCU component placement
    boot button aligned to plate cut
    [Didaktik rp2040.kicad_pcb, Didaktik rp2040.kicad_sch]
2023-04-13 MCU routing on rp2040 version
    [Didaktik rp2040.kicad_pcb, Didaktik rp2040.kicad_sch]
2023-05-29 updated BOM with correct parts
    [BOM-Didaktik multilayout.csv, BOM-Didaktik.csv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]
2023-06-30 added STEM project WIP
    [Didaktik STEM.kicad_pcb, Didaktik STEM.kicad_sch, Didaktik.kicad_pcb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]
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2024-02-12 added case files and updated the readme
    [Bottom.stl, Top.stl]
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
